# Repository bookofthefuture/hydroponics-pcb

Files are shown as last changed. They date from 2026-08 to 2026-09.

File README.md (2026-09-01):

# hydroponics-pcb

KiCad PCB designs for the hydroponics monitoring/control system on a two-tier
IKEA growing rack.

## Boards

| Board | Status | MCU | Purpose |
|---|---|-----|---|
| `tray-board` | fab-ready: ERC/DRC/schematic-parity clean, routed with GND pours + stitching, full JLC BOM (all Basic parts) / CPL / gerbers generated | socketed ESP32 30-pin DevKit | Per-tray sensor + display node. One per tray (top / bottom). |
| `reservoir-board` | not started | ESP32 (TBD) | Reservoir-side control: fill pumps, A/B + pH dosing pumps, level/EC/pH/temp sensing. |

Grow-lamp switching currently stays on the original ESP8266 `hydroponics_monitor`
node and is out of scope for these boards (may move to the reservoir board later).

## Tray board peripherals

| Function | Part | Bus | Notes |
|---|---|-----|---|
| ToF distance (water level) | VL53L0X / VL53L1X | I²C 3.3 V | Shared SDA/SCL |
| Air pressure (+ humidity/temp on BME) | BMP280 / BME280 | I²C 3.3 V | Shared SDA/SCL |
| Lux level | BH1750 | I²C 3.3 V | Shared SDA/SCL |
| Water temperature | DS18B20 | 1-Wire 3.3 V | Dedicated GPIO, 4.7 kΩ pull-up |
| User input | Rotary encoder + push switch | GPIO / quadrature | 3.3 V |
| Display | 2.4" ILI9341 240×320, resistive touch (XPT2046) + SD card | SPI (shared bus, separate CS lines) | LVGL, encoder-driven UI; SD card wired but not yet used by firmware |

Display connector (J2, 14-pin) pinout: VCC, GND, CS(D5), RESET(D4), DC(D2),
MOSI(D23), SCK(D18), LED(D15), MISO(D34), T_CLK(D18, shared), T_CS(D14),
T_DIN(D23, shared), T_DO(D34, shared), T_IRQ(D35). SD card connector (J3,
4-pin, separate from J2): CS(D19), MOSI(D23, shared), MISO(D34, shared),
SCK(D18, shared). New GPIOs used: 14, 19, 34, 35 — none of these were
previously assigned, so add them to the ESPHome configs without touching the
existing pin numbers.

No high-power switching on the tray board. An SP3485EN RS-485 transceiver
(120 Ω termination, direction pin on GPIO12) links the two tray boards to the
reservoir board.

## Comms

All three ESPs talk to Home Assistant over WiFi (ESPHome native API). The tray
boards *also* talk to the reservoir board over RS-485 — a local wired link so
fill-level reads and pump control don't depend on WiFi/HA. The reservoir is the
controlling node.

## Firmware

ESPHome configs live in the separate `ha-config` repo under `esphome/`
(`hydro-tray-top.yaml`, `hydro-tray-bottom.yaml`). The pin map is shared between
the schematic here and those configs — keep them in sync.

## Repo layout

```
tray-board/        KiCad project for the tray sensor board
reservoir-board/   (future) KiCad project for the reservoir board
shared-library/    custom symbol (New_Library) + footprint (Library.pretty)
                   library, referenced by both boards' sym-lib-table/
                   fp-lib-table via ${KIPRJMOD}/../../shared-library/ - keep
                   custom parts (ESP32 DevKit socket, display modules, etc.)
                   here rather than per-board copies, which drift silently
docs/              pin maps, block diagrams, datasheets
```

## Working with KiCad from the CLI

Requires KiCad 10.x (`kicad-cli`) plus the standard symbol/footprint libraries.

```
tools/fab.sh tray-board
```

runs ERC + DRC (fails on any error/warning) and writes a JLCPCB-ready set to
`tray-board/production/` (git-ignored — regenerated from source): gerbers
(Protel extensions) + separate PTH/NPTH Excellon drill files, zipped as
`<name>-gerbers.zip`; `<name>-cpl.csv` (SMD-only pick-and-place, DNP parts
excluded); `<name>-bom.csv` (DNP excluded, `LCSC Part #` column from each
part's `LCSC` schematic field). Parts you're sourcing/fitting yourself (e.g.
the socketed ESP32 module) should be marked Do Not Populate in the schematic
so they're left out of both the BOM and the CPL automatically.

It also runs `tools/check_pins.py`, which checks the MCU's pin usage for
hardware hazards ERC doesn't catch — currently ESP32 strapping pins (GPIO0,
2, 5, 12, 15) with an external pull that conflicts with their required
boot-time level, GPIO6-11 (internal flash, must never be used externally),
and UART0 (GPIO1/3, reserved for USB-serial). Fails the build on any
ERROR-severity finding; can also be run standalone:

```
tools/check_pins.py path/to/board.kicad_sch
```

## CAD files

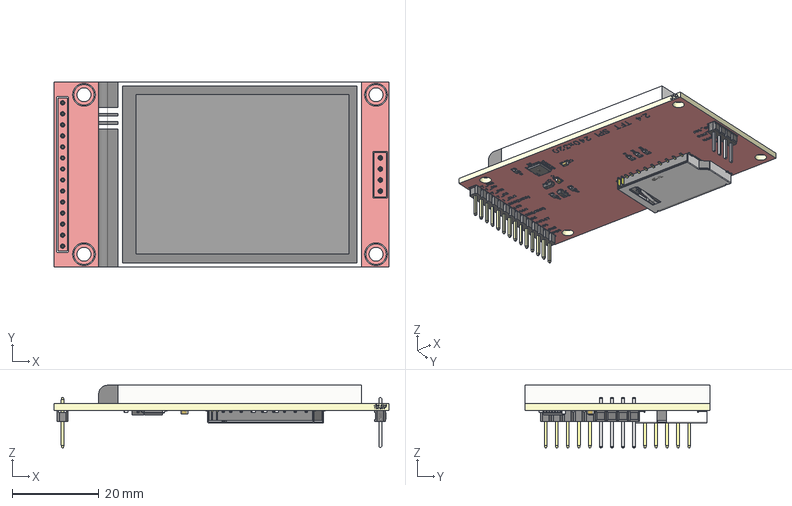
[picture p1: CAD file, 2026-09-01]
models/TFT LCD 2.4 inch ILI9341 touch.step
77.2 x 42.7 x 14.4 mm
Board~HwOR
TopSilkscreen~HwOR
BottomSilkscreen~HwOR
R0603~R0603~HwOR x 6
C0603~C0603_L1.6-W0.8-H0.8~HwOR x 2
HDR-TH_4P-P2.54-V-M~HDR-TH_4P-P2.54-M-LI-1X4P~HwOR
CONN-TH_PZ254V-11-14P~CONN-TH_PZ254V-11-14P~HwOR
SOT-23-3_L2.9-W1.3-P1.90-LS2.4-BR~SOT-23-3P_L2.9-W1.3-H1.0-LS2.4-P0.9 5~HwOR x 2
SD-CARD-SMD_SD-CARD-11P~SD-CARD-SMD_SD-CARD-11P~HwOR
TSSOP-16_L5.0-W4.4-P0.65-LS6.4-BL~TSSOP-16_L5.0-W4.4-H1.0-LS6.4-P0.65 ~HwOR
text

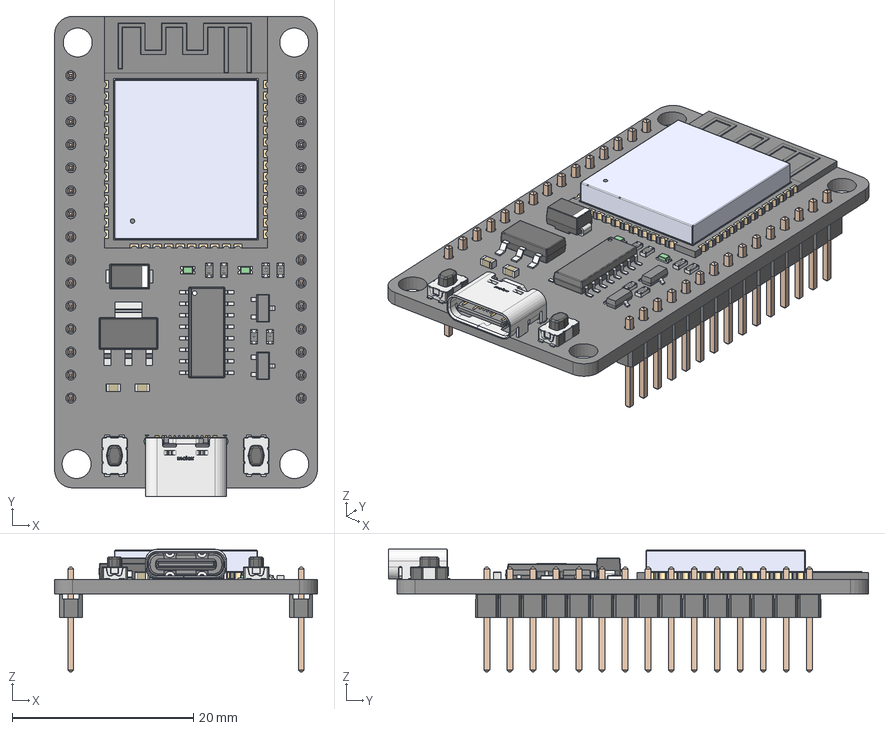
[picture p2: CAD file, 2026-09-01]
models/esp32_30pin.step
29.0 x 53.0 x 13.5 mm
6130xx11121_PIN x 30
SMA
0603 cap x 2
C&K - KMR7 x 2
0603 resistor x 6
LED 0603 Lens GREEN x 2
LED 0603 Base GREEN x 2
SOT-23-3 x 2
Leader x 16
SOT-223
Notch
Molex

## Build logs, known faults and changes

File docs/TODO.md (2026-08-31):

# Docs / tooling TODO

## Automated project documentation (web format)

**Goal:** generate a browsable project site from the repo, and make updating it part
of the deployment process rather than a separate chore.

Content it should pull together:

- Project overview / block diagram (tray boards + reservoir board + HA, WiFi + RS-485).
- Per-board pages: schematic render, PCB render (front/back), board specs
  (layers, size, thickness), revision.
- Links to artifacts: this repo, per-board 3D/STEP files, gerber zips, BOM, P&P.
- Deployment / assembly manual — for Tom and for anyone else building one:
  BOM sourcing, assembly order, flashing the ESPHome firmware, wiring the RS-485
  bus and sensor harnesses, first-power checks, calibration (EC/pH, ToF zero).

Ideas on how:

- `kicad-cli pcb render` + `pcb export svg/pdf` + `sch export svg` for the images.
- `kicad-cli pcb export step` for the 3D (needs `kicad-packages3d` installed).
- Static site — plain HTML, or MkDocs / Eleventy — published to GitHub Pages.
- A `tools/docs.sh` that regenerates images + site from source; call it from the
  release/deploy flow so docs can't drift from the hardware.
- Version the deployment manual alongside the board revision it describes.

Not started — captured 2026-08-28.

## Tray-board display connector footprint (for the redesign)

`docs/datasheets/MSP2401_2.4in_TFT_touch_SD_mechanical.pdf` — mechanical
drawing for the LCD Wiki MSP2401/MSP2402 2.4" ILI9341+XPT2046 module.
Confirmed against the physical board (2026-08-31) — this is the correct
footprint, not just a probable match.

Dimensioned numbers from this drawing, all confirmed against physical
measurement:
- PCB outline: 42.72 x 77.18mm
- Main 14-pin header (J2): 2.54mm pitch, 33.02mm span (13 gaps), pin 1
  at X=4.85mm, Y=75.18mm (2.00mm up from the bottom edge) from the
  top-left PCB corner
- SD card header (J4): 4 pins, 2.54mm pitch, pin 1 at X=17.23mm,
  Y=3.00mm from the top-left PCB corner (same row as the two top
  mounting holes)
- 4 mounting holes: 3.20mm drill / 4.70mm pad, at 36.72mm x 67.26mm
  hole-to-hole spacing, inset 3.00mm from each edge

All of the above is already built as a footprint:
`shared-library/Library.pretty/Display_MSP2401_2.4in_Touch.kicad_mod`
(outline, mounting holes, J2 pins 1-14, J4 pins SD1-SD4) — use it
directly for correct connector spacing in the redesign rather than
re-deriving these numbers.

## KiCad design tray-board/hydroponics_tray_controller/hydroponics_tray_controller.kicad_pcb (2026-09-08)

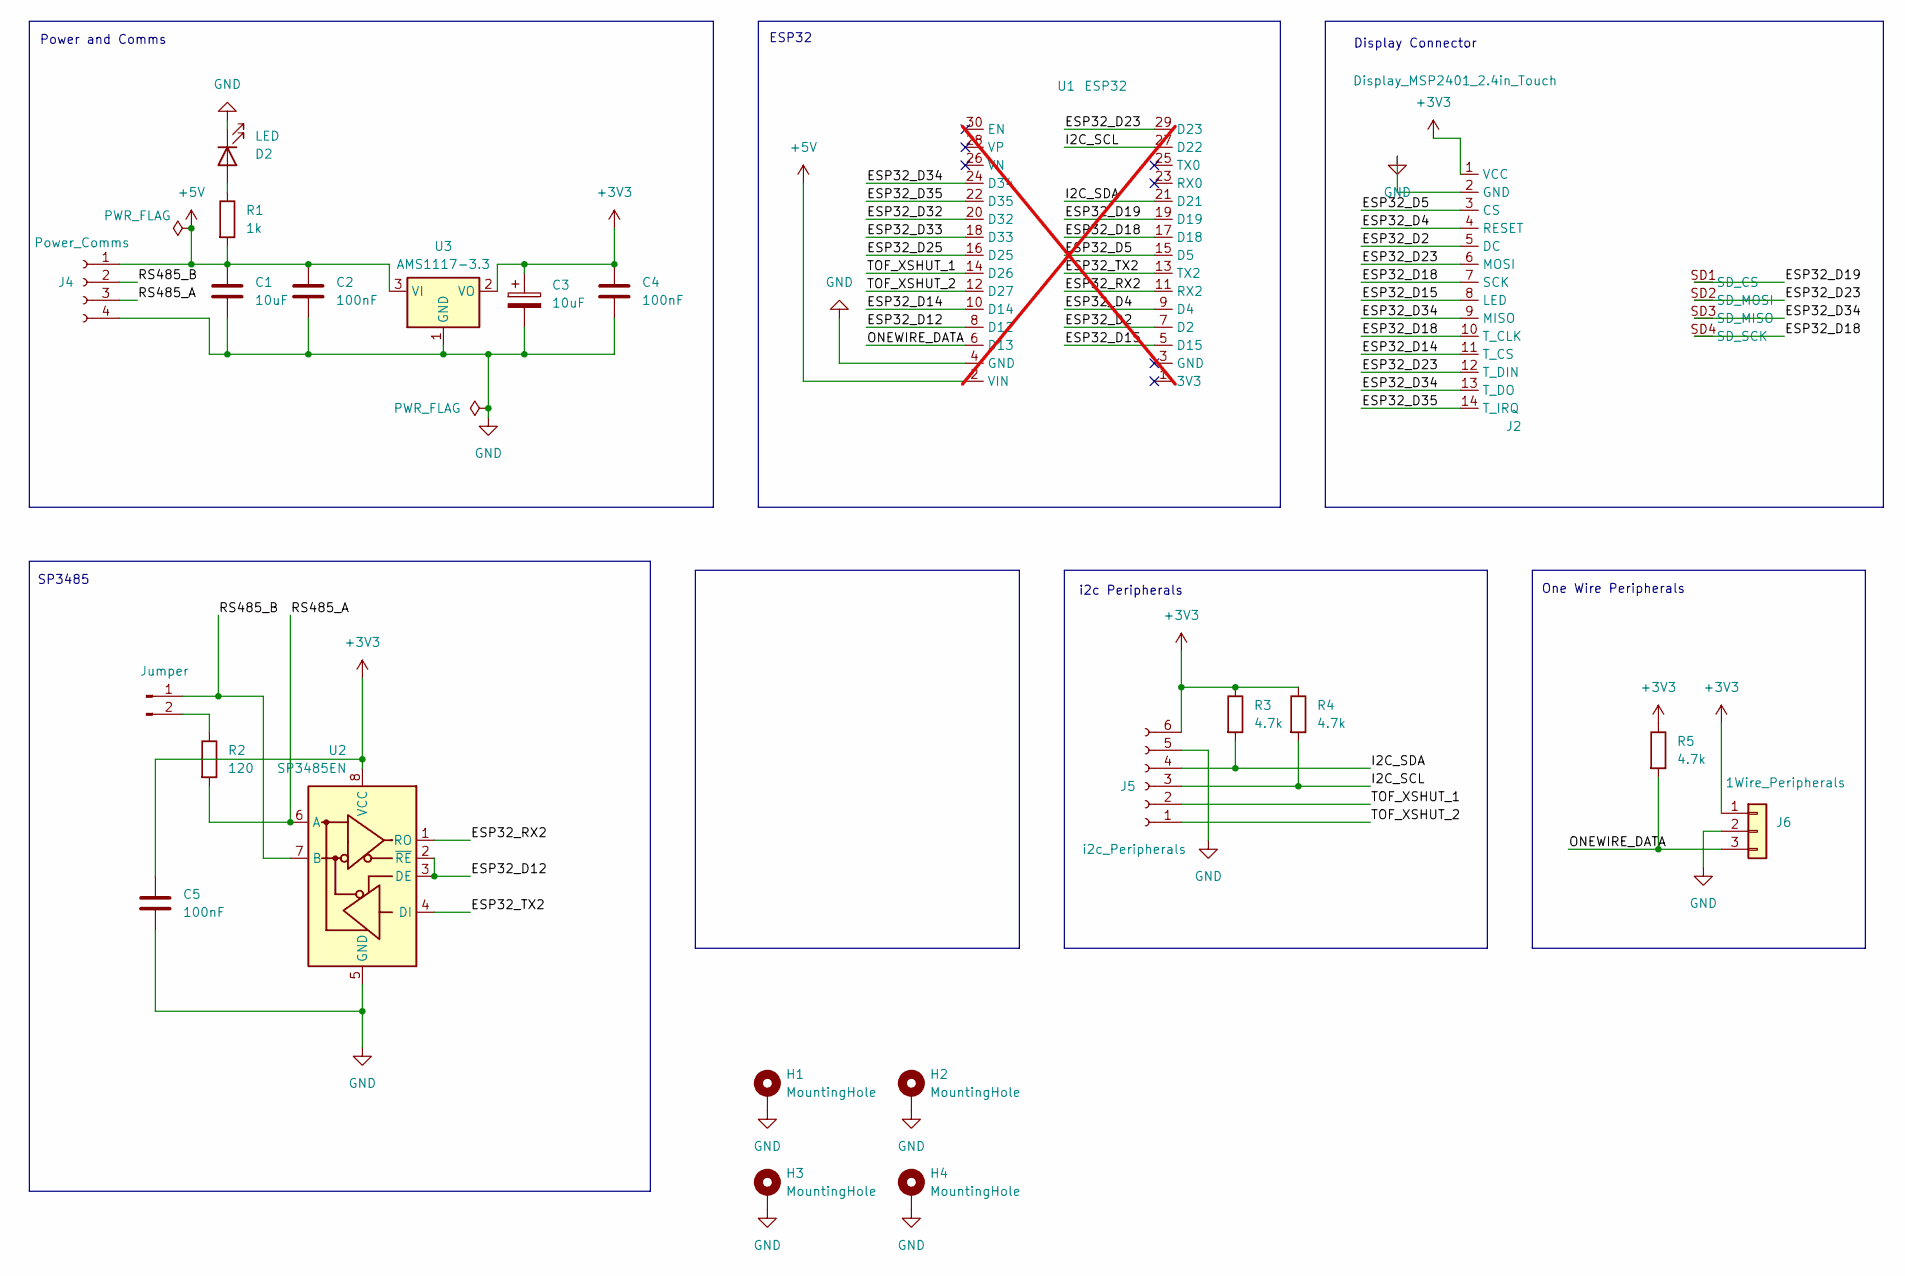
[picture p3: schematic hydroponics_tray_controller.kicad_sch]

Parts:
C1: 10uF; C_1206_3216Metric; LCSC C13585
C2, C4, C5: 100nF; C_0805_2012Metric; LCSC C49678
C3: 10uF; C_0805_2012Metric; LCSC C15850
D2: LED; LED_0805_2012Metric; LCSC C2297
H1, H2, H3, H4: MountingHole; MountingHole_3.2mm_M3_Pad_Via
J1: Jumper; PinHeader_1x02_P2.54mm_Vertical
J2: Display_MSP2401_2.4in_Touch
J4: Power_Comms; JST_XH_B4B-XH-A_1x04_P2.50mm_Vertical
J5: i2c_Peripherals; JST_XH_B6B-XH-A_1x06_P2.50mm_Vertical
J6: 1Wire_Peripherals; JST_XH_B3B-XH-A_1x03_P2.50mm_Vertical
R1: 1k; R_0805_2012Metric; LCSC C17513
R2: 120; R_0805_2012Metric; LCSC C17437
R3, R4, R5: 4.7k; R_0805_2012Metric; LCSC C17673
U1: ESP32; ESP32_DevKit_30Pin; not fitted
U2: SP3485EN; SOIC-8_3.9x4.9mm_P1.27mm; LCSC C8963
U3: AMS1117-3.3; SOT-223-3_TabPin2; LCSC C6186

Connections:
+3V3: C3.1, C4.1, C5.1, J2.1 (VCC), J5.6, J6.1, R3.1, R4.1, R5.1, U2.8 (VCC), U3.2 (VO)
+5V: C1.1, C2.1, J4.1, R1.2, U1.2 (VIN), U3.3 (VI)
/ESP32_D2: J2.5 (DC), U1.7 (D2)
/ESP32_D4: J2.4 (RESET), U1.9 (D4)
/ESP32_D5: J2.3 (CS), U1.15 (D5)
/ESP32_D12: U1.8 (D12), U2.2 (~RE), U2.3 (DE)
/ESP32_D14: J2.11 (T_CS), U1.10 (D14)
/ESP32_D15: J2.8 (LED), U1.5 (D15)
/ESP32_D18: J2.7 (SCK), J2.10 (T_CLK), J2.SD4 (SD_SCK), U1.17 (D18)
/ESP32_D19: J2.SD1 (SD_CS), U1.19 (D19)
/ESP32_D23: J2.6 (MOSI), J2.12 (T_DIN), J2.SD2 (SD_MOSI), U1.29 (D23)
/ESP32_D25: U1.16 (D25)
/ESP32_D32: U1.20 (D32)
/ESP32_D33: U1.18 (D33)
/ESP32_D34: J2.9 (MISO), J2.13 (T_DO), J2.SD3 (SD_MISO), U1.24 (D34)
/ESP32_D35: J2.14 (T_IRQ), U1.22 (D35)
/ESP32_RX2: U1.11 (RX2), U2.1 (RO)
/ESP32_TX2: U1.13 (TX2), U2.4 (DI)
/I2C_SCL: J5.3, R4.2, U1.27 (D22)
/I2C_SDA: J5.4, R3.2, U1.21 (D21)
/ONEWIRE_DATA: J6.3, R5.2, U1.6 (D13)
/RS485_A: J4.3, R2.2, U2.6 (A)
/RS485_B: J1.1, J4.2, U2.7 (B)
/TOF_XSHUT_1: J5.2, U1.14 (D26)
/TOF_XSHUT_2: J5.1, U1.12 (D27)
GND: C1.2, C2.2, C3.2, C4.2, C5.2, D2.1 (K), H1.1 (1_1), H2.1 (1_1), H3.1 (1_1), H4.1 (1_1), J2.2 (GND), J4.4, J5.5, J6.2, U1.4 (GND), U2.5 (GND), U3.1 (GND)
unnamed: D2.2 (A), R1.1
unnamed: J1.2, R2.1

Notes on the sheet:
One Wire Peripherals
SP3485
ESP32
Display Connector
i2c Peripherals
Power and Comms

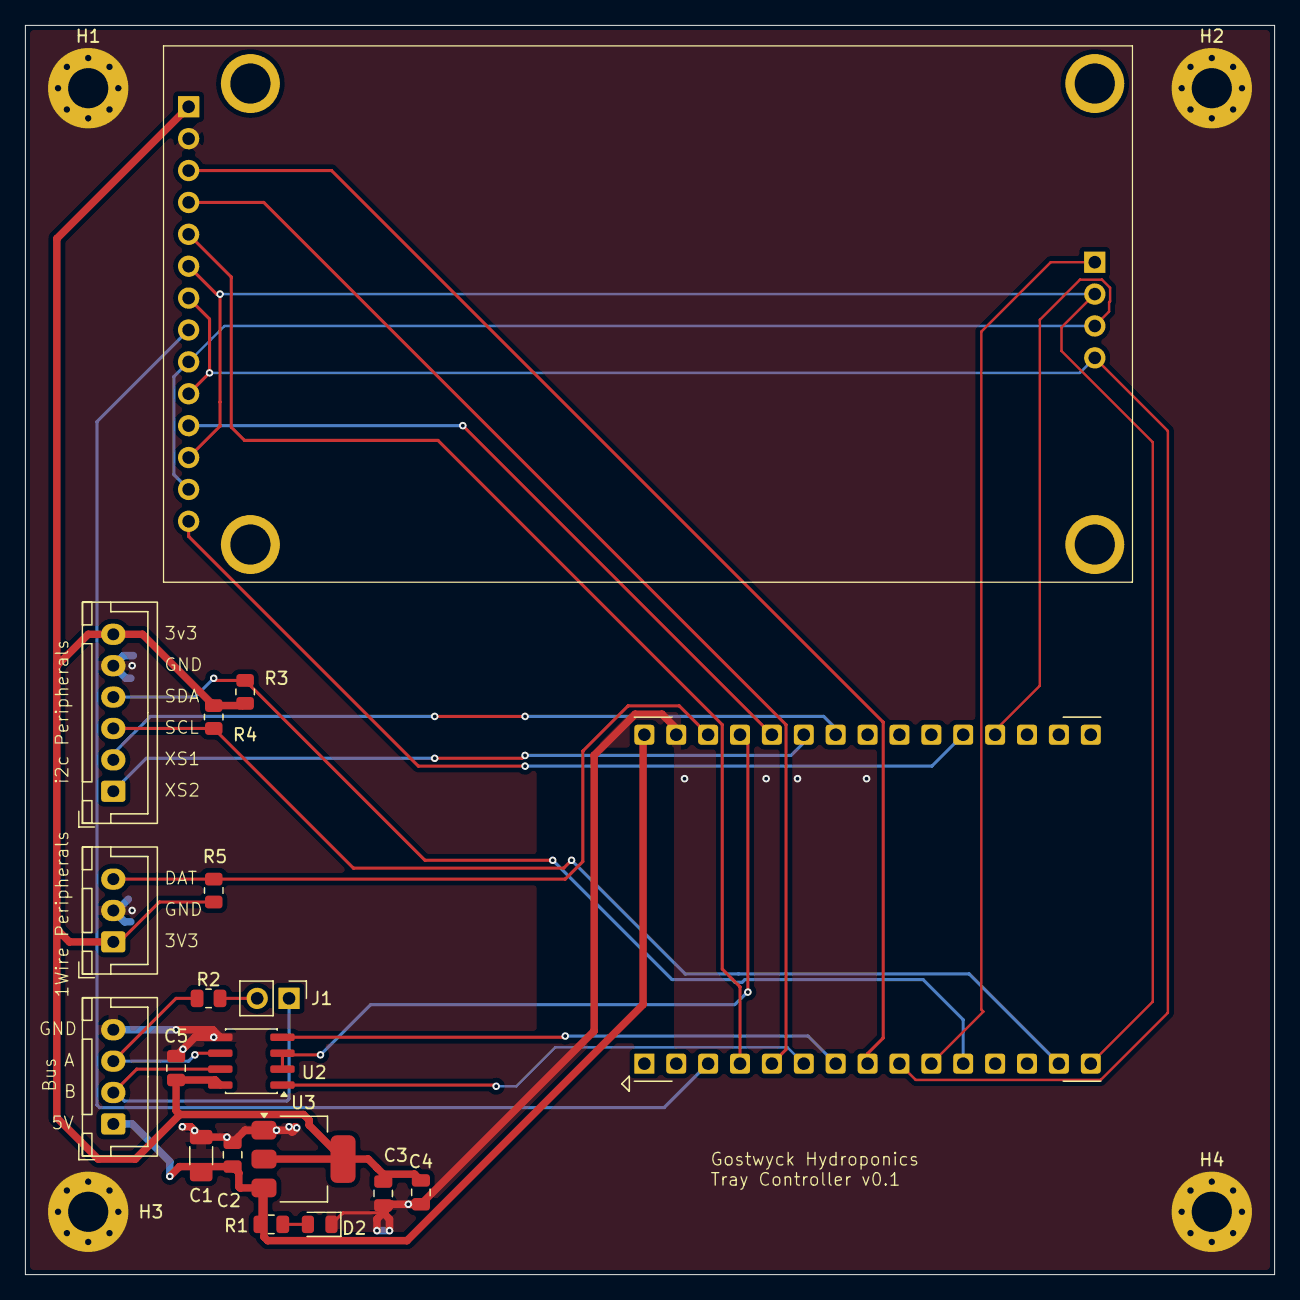
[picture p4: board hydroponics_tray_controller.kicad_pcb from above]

Board: 2 copper layers, 99.5 x 99.5 mm, 23 parts (0 on the bottom side), 25 nets.

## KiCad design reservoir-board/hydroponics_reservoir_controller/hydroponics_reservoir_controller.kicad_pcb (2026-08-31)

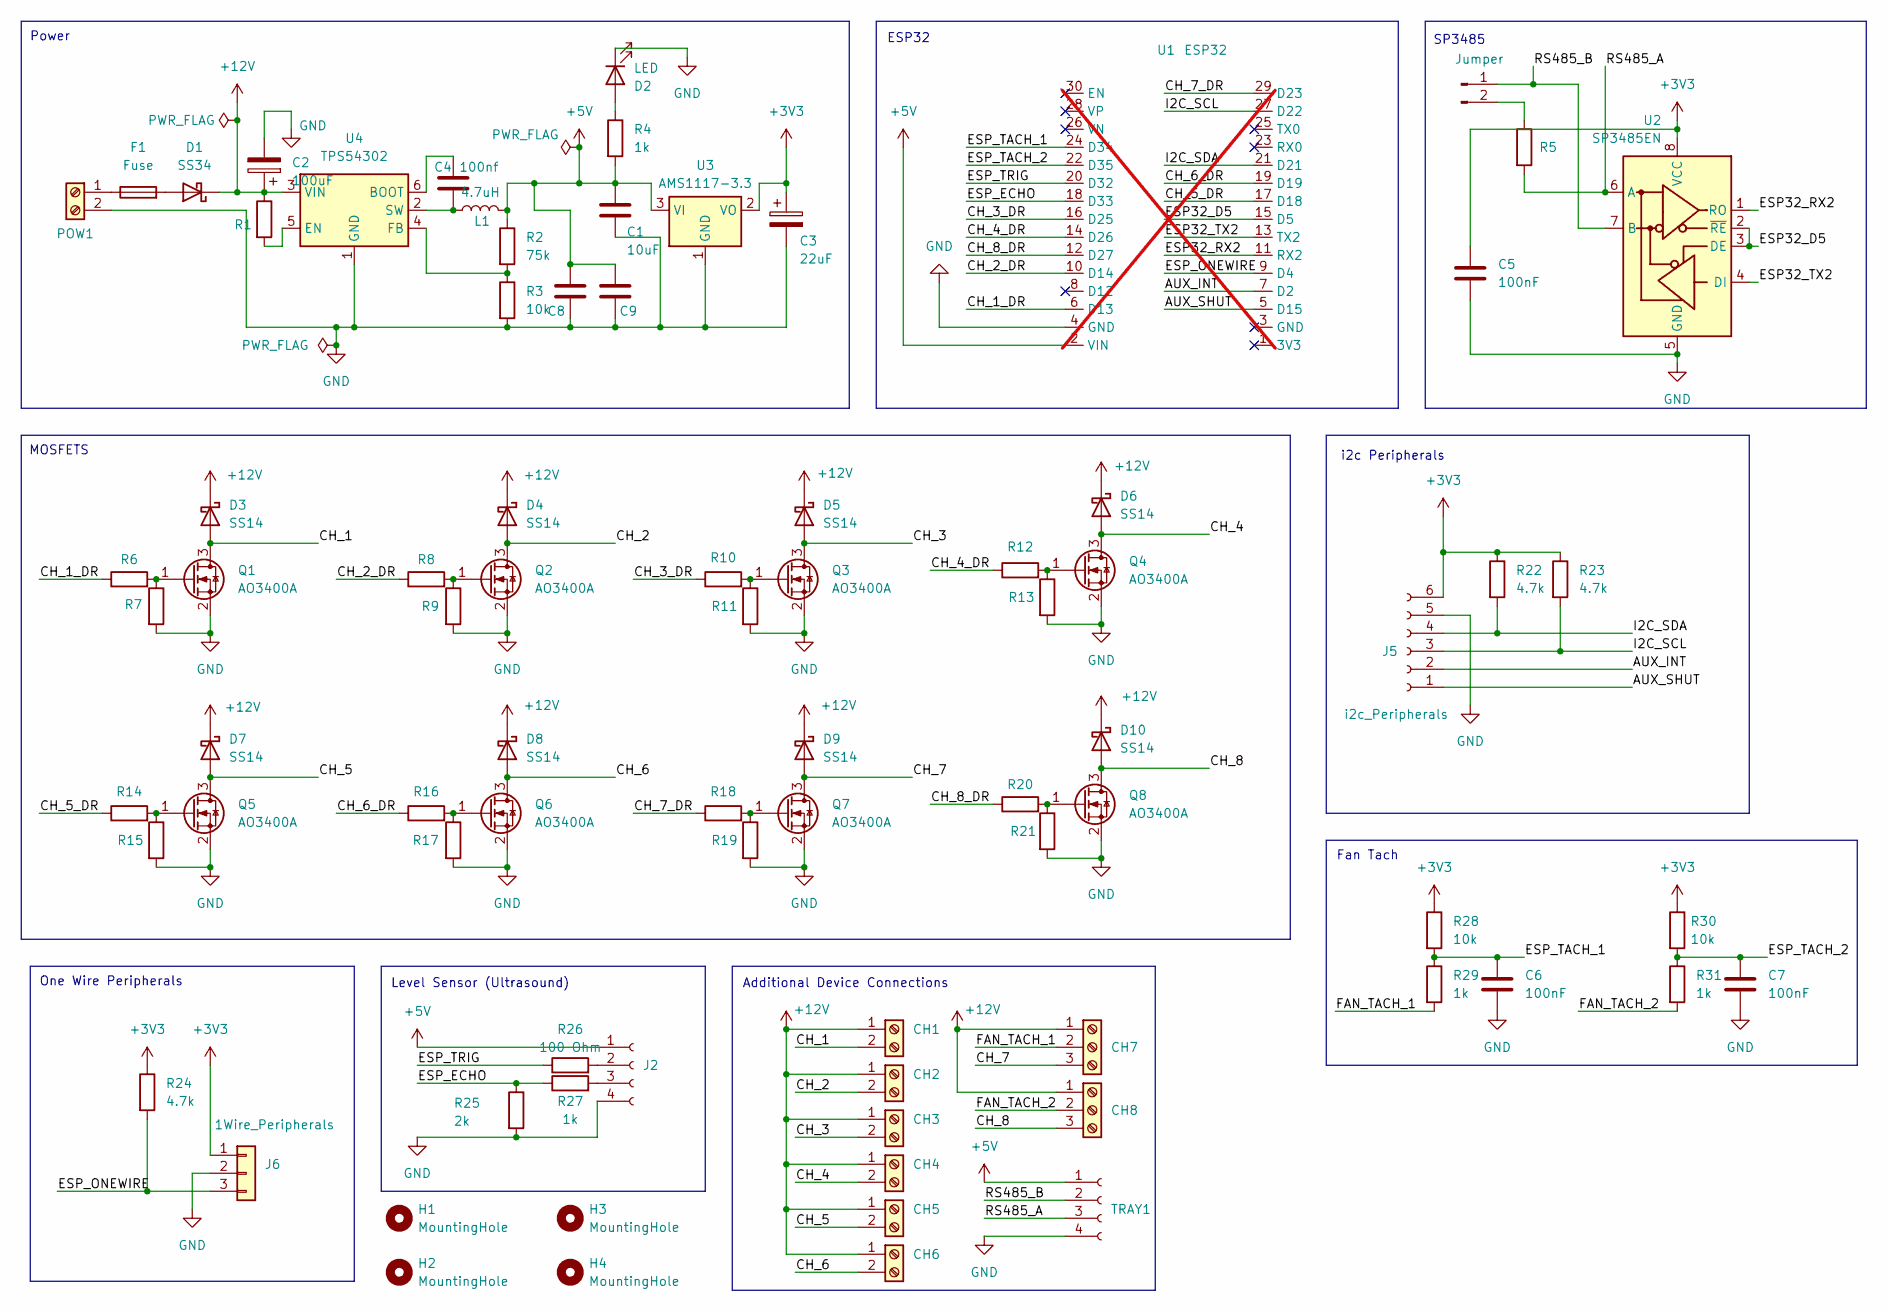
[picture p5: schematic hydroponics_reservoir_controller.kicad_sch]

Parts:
C1: 10uF; C_1206_3216Metric; LCSC C2443257
C2: 100uF; CP_Elec_6.3x7.7; LCSC C970685
C3: 22uF; CP_EIA-3528-21_Kemet-B; LCSC C24518
C4: 100nf; C_1206_3216Metric; LCSC C93194
C5, C6, C7: 100nF; C_0805_2012Metric; LCSC C83055
C8, C9: 22uF; C_1206_3216Metric; LCSC C105213
CH1, CH2, CH3, CH4, CH5, CH6: Screw_Terminal_01x02; TerminalBlock_Phoenix_PT-1,5-2-3.5-H_1x02_P3.50mm_Horizontal; LCSC C474892
CH7, CH8: Screw_Terminal_01x03; TerminalBlock_Phoenix_PT-1,5-3-3.5-H_1x03_P3.50mm_Horizontal; LCSC C474893
D1: SS34; D_SMA; LCSC C8678
D2: LED; LED_0805_2012Metric; LCSC C84260
D3, D4, D5, D6, D7, D8, D9, D10: SS14; D_SMA; LCSC C1508
F1: Fuse; Fuse_2920_7451Metric; LCSC C207091
H1, H2, H3, H4: MountingHole; MountingHole_3.2mm_M3_Pad
J1: Jumper; PinHeader_1x02_P2.54mm_Vertical; LCSC C36717
J2: Conn_01x04_Socket; JST_XH_B4B-XH-A_1x04_P2.50mm_Vertical; LCSC C144395
J5: i2c_Peripherals; JST_XH_B6B-XH-A_1x06_P2.50mm_Vertical; LCSC C144397
J6: 1Wire_Peripherals; JST_XH_B3B-XH-A_1x03_P2.50mm_Vertical; LCSC C144394
L1: 4.7uH; L_Bourns_SRP6060FA; LCSC C2047389
POW1: Screw_Terminal_01x02; TerminalBlock_Phoenix_PT-1,5-2-5.0-H_1x02_P5.00mm_Horizontal; LCSC C474881
Q1, Q2, Q3, Q4, Q5, Q6, Q7, Q8: AO3400A; SOT-23; LCSC C20917
R1: 100k; R_0805_2012Metric; LCSC C17407
R2: 75k; R_0805_2012Metric; LCSC C17819
R3, R7, R9, R11, R13, R15, R17, R19, R21, R28, R30: 10k; R_0805_2012Metric; LCSC C17414
R4, R27, R29, R31: 1k; R_0805_2012Metric; LCSC C17513
R5: 120 Ohm; R_0805_2012Metric; LCSC C17437
R6, R8, R10, R12, R14, R16, R18, R20, R26: 100 Ohm; R_0805_2012Metric; LCSC C17408
R22, R23, R24: 4.7k; R_0805_2012Metric; LCSC C17673
R25: 2k; R_0805_2012Metric; LCSC C17604
TRAY1: Conn_01x04_Socket; JST_XH_B4B-XH-A_1x04_P2.50mm_Vertical; LCSC C144395
U1: ESP32; ESP32_DevKit_30Pin; not fitted
U2: SP3485EN; SOIC-8_3.9x4.9mm_P1.27mm; LCSC C8963
U3: AMS1117-3.3; SOT-223-3_TabPin2; LCSC C6186
U4: TPS54302; SOT-23-6; LCSC C311983

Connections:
+3V3: C3.1, C5.1, J5.6, J6.1, R22.1, R23.1, R24.1, R28.1, R30.1, U2.8 (VCC), U3.2 (VO); also elsewhere on the board
+5V: C1.1, C8.1, C9.1, J2.1, L1.2, R2.1, R4.2, TRAY1.1, U1.2 (VIN), U3.3 (VI); also elsewhere on the board
/AUX_INT: J5.2, U1.7 (D2); also elsewhere on the board
/AUX_SHUT: J5.1, U1.5 (D15); also elsewhere on the board
/CH_1: CH1.2, D3.2 (A), Q1.3 (D)
/CH_1_DR: R6.1, U1.6 (D13)
/CH_2: CH2.2, D4.2 (A), Q2.3 (D)
/CH_2_DR: R8.1, U1.10 (D14)
/CH_3: CH3.2, D5.2 (A), Q3.3 (D)
/CH_3_DR: R10.1, U1.16 (D25)
/CH_4: CH4.2, D6.2 (A), Q4.3 (D)
/CH_4_DR: R12.1, U1.14 (D26)
/CH_5: CH5.2, D7.2 (A), Q5.3 (D)
/CH_5_DR: R14.1, U1.17 (D18)
/CH_6: CH6.2, D8.2 (A), Q6.3 (D)
/CH_6_DR: R16.1, U1.19 (D19)
/CH_7: CH7.3, D9.2 (A), Q7.3 (D)
/CH_7_DR: R18.1, U1.29 (D23)
/CH_8: CH8.3, D10.2 (A), Q8.3 (D)
/CH_8_DR: R20.1, U1.12 (D27)
/ESP32_D5: U1.15 (D5), U2.2 (~RE), U2.3 (DE)
/ESP32_RX2: U1.11 (RX2), U2.1 (RO)
/ESP32_TX2: U1.13 (TX2), U2.4 (DI)
/ESP_ECHO: R25.1, R27.1, U1.18 (D33)
/ESP_ONEWIRE: J6.3, R24.2, U1.9 (D4); also elsewhere on the board
/ESP_TACH_1: C6.1, R28.2, R29.1, U1.24 (D34)
/ESP_TACH_2: C7.1, R30.2, R31.1, U1.22 (D35)
/ESP_TRIG: R26.1, U1.20 (D32)
/FAN_TACH_1: CH7.2, R29.2
/FAN_TACH_2: CH8.2, R31.2
/I2C_SCL: J5.3, R23.2, U1.27 (D22); also elsewhere on the board
/I2C_SDA: J5.4, R22.2, U1.21 (D21); also elsewhere on the board
/RS485_A: R5.2, TRAY1.3, U2.6 (A); also elsewhere on the board
/RS485_B: J1.1, TRAY1.2, U2.7 (B); also elsewhere on the board
GND: C1.2, C2.2, C3.2, C5.2, C6.2, C7.2, C8.2, C9.2, D2.1 (K), J2.4, J5.5, J6.2, POW1.2, Q1.2 (S), Q2.2 (S), Q3.2 (S), Q4.2 (S), Q5.2 (S), Q6.2 (S), Q7.2 (S), Q8.2 (S), R3.2, R7.2, R9.2, R11.2, R13.2, R15.2, R17.2, R19.2, R21.2, R25.2, TRAY1.4, U1.4 (GND), U2.5 (GND), U3.1 (GND), U4.1 (GND); also elsewhere on the board
unnamed: D1.2 (A), F1.2
unnamed: D2.2 (A), R4.1
unnamed: J1.2, R5.1
unnamed 38: J2.2, R26.2; also elsewhere on the board
unnamed 39: J2.3, R27.2; also elsewhere on the board
unnamed: Q1.1 (G), R6.2, R7.1
unnamed: Q2.1 (G), R8.2, R9.1
unnamed: Q3.1 (G), R10.2, R11.1
unnamed: Q4.1 (G), R12.2, R13.1
unnamed: Q5.1 (G), R14.2, R15.1
unnamed: Q6.1 (G), R16.2, R17.1
unnamed: Q7.1 (G), R18.2, R19.1
unnamed: Q8.1 (G), R20.2, R21.1
unnamed: C4.1, U4.6 (BOOT)
unnamed: R1.2, U4.5 (EN)
unnamed: R2.2, R3.1, U4.4 (FB)
unnamed: C4.2, L1.1, U4.2 (SW)

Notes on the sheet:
One Wire Peripherals
Additional Device Connections
SP3485
ESP32
MOSFETS
Level Sensor (Ultrasound)
Fan Tach
i2c Peripherals
Power

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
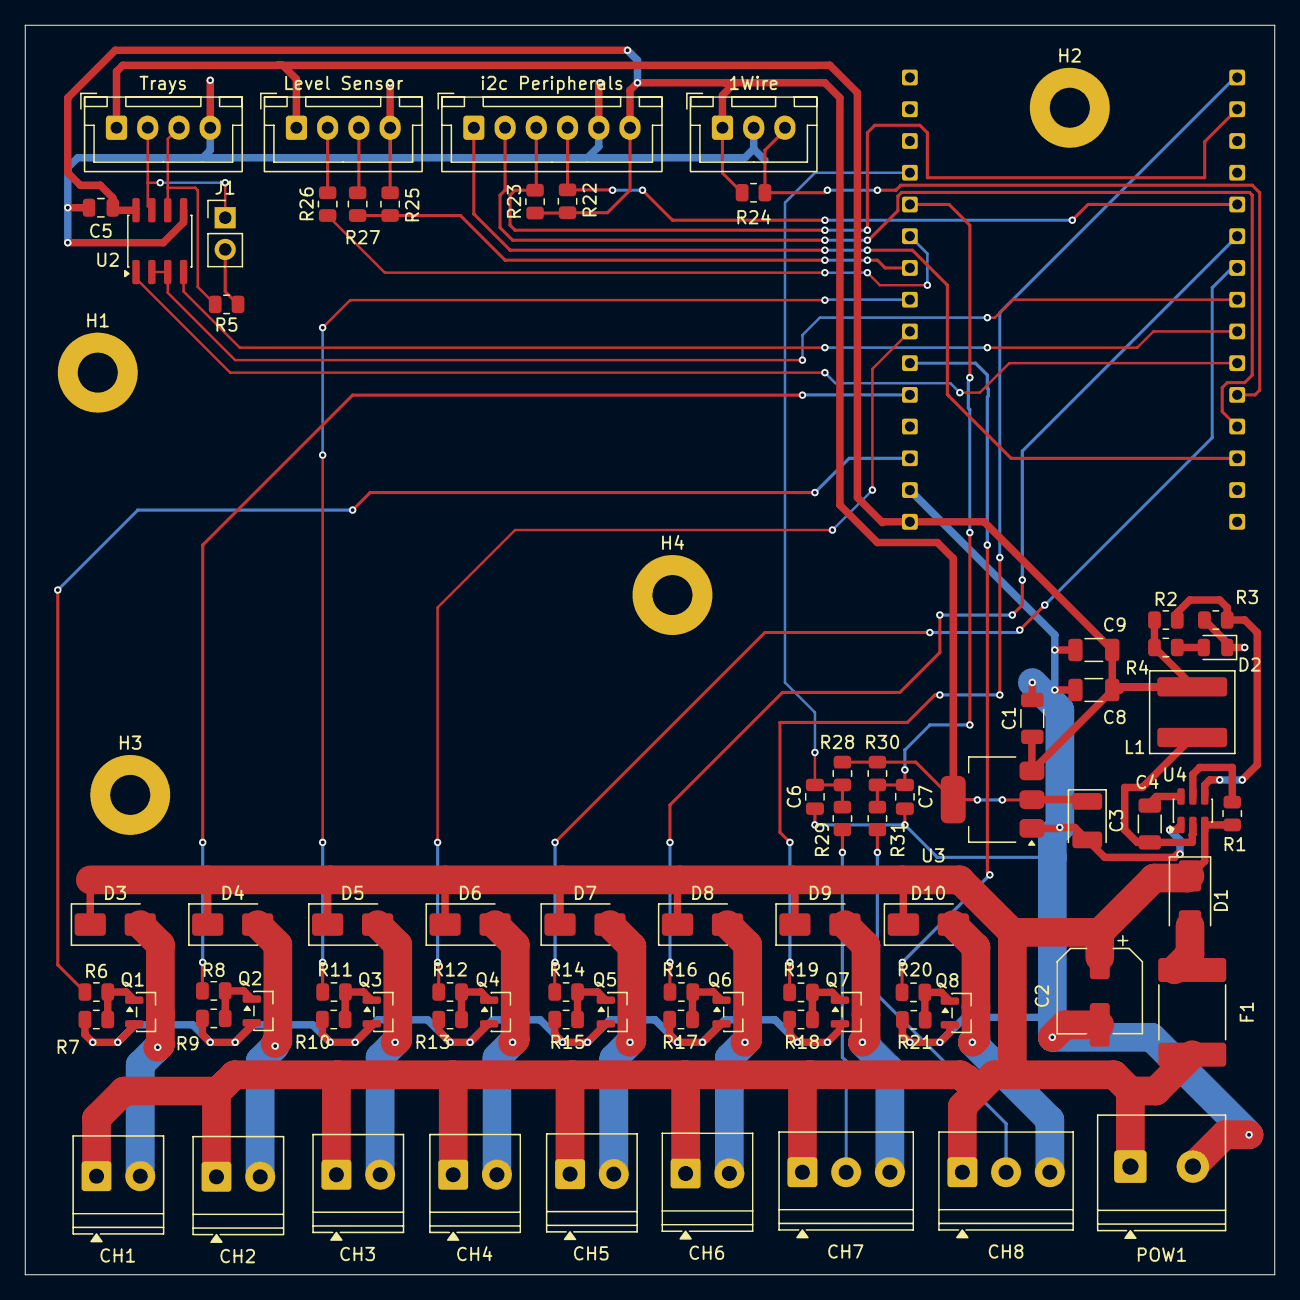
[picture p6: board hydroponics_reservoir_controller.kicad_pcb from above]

Board: 2 copper layers, 100.0 x 100.0 mm, 82 parts (0 on the bottom side), 53 nets.

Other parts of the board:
1Wire: 1Wire_Peripherals; JST_XH_B3B-XH-A_1x03_P2.50mm_Vertical
Level Sensor: Conn_01x04_Socket; JST_XH_B4B-XH-A_1x04_P2.50mm_Vertical
Trays: Conn_01x04_Socket; JST_XH_B4B-XH-A_1x04_P2.50mm_Vertical
i2c Peripherals: i2c_Peripherals; JST_XH_B6B-XH-A_1x06_P2.50mm_Vertical

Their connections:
+3V3: 1Wire.1, i2c Peripherals.6; also elsewhere on the board
+5V: Level Sensor.1, Trays.1; also elsewhere on the board
/AUX_INT: i2c Peripherals.2; also elsewhere on the board
/AUX_SHUT: i2c Peripherals.1; also elsewhere on the board
/ESP_ONEWIRE: 1Wire.3; also elsewhere on the board
/I2C_SCL: i2c Peripherals.3; also elsewhere on the board
/I2C_SDA: i2c Peripherals.4; also elsewhere on the board
/RS485_A: Trays.3; also elsewhere on the board
/RS485_B: Trays.2; also elsewhere on the board
GND: 1Wire.2, Level Sensor.4, Trays.4, i2c Peripherals.5; also elsewhere on the board
unnamed 38: Level Sensor.2; also elsewhere on the board
unnamed 39: Level Sensor.3; also elsewhere on the board

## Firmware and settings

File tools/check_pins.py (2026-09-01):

#!/usr/bin/env python3
"""
Check MCU pin usage in a KiCad schematic for hardware-boot / strapping-pin
hazards before it goes to production. Currently has a rule set for the
ESP32 (strapping pins, input-only pins, reserved-flash pins, UART0).

Usage:
    tools/check_pins.py <path-to.kicad_sch>

Exits non-zero if any ERROR-severity issue is found (matches the
ERC/DRC convention used by tools/fab.sh).
"""

import os
import re
import subprocess
import sys
import tempfile
from pathlib import Path

# --- ESP32 pin rules -------------------------------------------------------
# Keyed by the pin "name" as it appears in the schematic symbol (before the
# trailing "_<pinnumber>" KiCad appends to pinfunction in the netlist).
#
# bad_pull: "up" | "down" | None  - an external pull in this direction on the
#   net conflicts with the pin's required state during the ESP32 boot/reset
#   window (before firmware takes over).
STRAPPING_RULES = {
    "D0": {
        "severity": "error",
        "bad_pull": "down",
        "note": "GPIO0 (BOOT) must be HIGH at reset for normal boot; an "
                "external pull-down (or hard tie to GND) forces download "
                "mode and the board will not run firmware.",
    },
    "D2": {
        "severity": "error",
        "bad_pull": "up",
        "note": "GPIO2 must be LOW or floating at reset for normal SPI "
                "boot; an external pull-up can prevent the board from "
                "booting.",
    },
    "D5": {
        "severity": "warning",
        "bad_pull": "down",
        "note": "GPIO5 should be HIGH at reset (affects VSPI/boot timing "
                "default on some modules); an external pull-down may cause "
                "intermittent boot issues.",
    },
    "D12": {
        "severity": "error",
        "bad_pull": "up",
        "note": "GPIO12 (MTDI) selects flash voltage at reset. An external "
                "pull-up forces 1.8V flash detection and will break boot "
                "on the (standard) 3.3V-flash modules this project uses.",
    },
    "D15": {
        "severity": "info",
        "bad_pull": None,
        "note": "GPIO15 (MTDO) LOW silences the ROM boot log on UART0; "
                "HIGH (its internal pull-up default) is functionally fine, "
                "just noisier on the console.",
    },
}

INPUT_ONLY_PINS = {"D34", "D35", "VP", "VN"}
UART0_PINS = {"RX0", "TX0"}
RESERVED_FLASH_PINS = {"D6", "D7", "D8", "D9", "D10", "D11"}

POWER_NET_POSITIVE = re.compile(r"^\+?(3V3|5V|VCC|VDD)$", re.I)
POWER_NET_GROUND = re.compile(r"^(GND|AGND|DGND)$", re.I)


def run_netlist_export(sch_path: Path, out_path: Path) -> None:
    kicad_cli = os.environ.get("KICAD_CLI", "kicad-cli")
    subprocess.run(
        [
            kicad_cli, "sch", "export", "netlist",
            "--format", "kicadsexpr",
            "-o", str(out_path),
            str(sch_path),
        ],
        check=True,
        capture_output=True,
        text=True,
    )


def parse_netlist(text: str):
    """Return (components: {ref: part_name}, nets: [{name, nodes:[(ref,pin,pinfunction,pintype)]}])."""
    components = {}
    for comp_block in re.finditer(
        r'\(comp\s*\n\s*\(ref "([^"]+)"\).*?\(libsource\s*\n\s*\(lib "[^"]*"\)\s*\n\s*\(part "([^"]*)"\)',
        text, re.S,
    ):
        ref, part = comp_block.groups()
        components[ref] = part

    nets = []
    net_blocks = re.split(r"\n\t\t\(net\n", text)
    for block in net_blocks[1:]:
        block = "\t\t(net\n" + block
        name_m = re.search(r'\(name "([^"]*)"\)', block)
        name = name_m.group(1) if name_m else ""
        nodes = re.findall(
            r'\(ref "([^"]+)"\)\s*\(pin "([^"]+)"\)\s*(?:\(pinfunction "([^"]*)"\)\s*)?\(pintype "([^"]*)"\)',
            block,
        )
        nets.append({"name": name, "nodes": nodes})
    return components, nets


def pin_name_from_function(pinfunction: str, pin_number: str) -> str:
    if not pinfunction:
        return pin_number
    suffix = f"_{pin_number}"
    if pinfunction.endswith(suffix):
        return pinfunction[: -len(suffix)]
    return pinfunction


def main():
    if len(sys.argv) != 2:
        print(__doc__)
        sys.exit(2)

    sch_path = Path(sys.argv[1]).resolve()
    if not sch_path.exists():
        print(f"error: {sch_path} not found", file=sys.stderr)
        sys.exit(2)

    with tempfile.TemporaryDirectory() as tmp:
        nl_path = Path(tmp) / "check_pins.net"
        try:
            run_netlist_export(sch_path, nl_path)
        except subprocess.CalledProcessError as e:
            print("error: kicad-cli netlist export failed", file=sys.stderr)
            print(e.stderr, file=sys.stderr)
            sys.exit(2)
        text = nl_path.read_text()

    components, nets = parse_netlist(text)

    mcu_refs = [ref for ref, part in components.items() if "esp32" in part.lower()]
    if not mcu_refs:
        print("check_pins: no ESP32 symbol found in this schematic — nothing to check.")
        sys.exit(0)

    # net lookup: (ref, pin) -> net dict, for tracing pull-resistor legs
    pin_to_net = {}
    for net in nets:
        for ref, pin, _pf, _pt in net["nodes"]:
            pin_to_net[(ref, pin)] = net

    findings = []  # (severity, message)

    checked_strapping = []  # (pname, ref, pin) with no hazard found

    for net in nets:
        mcu_nodes = [n for n in net["nodes"] if n[0] in mcu_refs]
        if not mcu_nodes:
            continue
        # KiCad gives every truly-unconnected pin its own placeholder net
        # named "unconnected-(...)" — nothing is actually wired there.
        is_unconnected = net["name"].startswith("unconnected-")

        for ref, pin, pinfunction, _pintype in mcu_nodes:
            pname = pin_name_from_function(pinfunction, pin)

            if is_unconnected:
                continue

            if pname in RESERVED_FLASH_PINS:
                findings.append((
                    "error",
                    f"{ref} pin {pin} ({pname}) is one of the ESP32's internal "
                    f"SPI-flash pins (GPIO6-11) and is wired to net "
                    f"'{net['name']}'. These must never be used externally on "
                    f"a module with integrated flash.",
                ))
                continue

            if pname in UART0_PINS:
                findings.append((
                    "warning",
                    f"{ref} pin {pin} ({pname}) is UART0 (USB-serial console "
                    f"/ flashing) and is wired to net '{net['name']}'. Using "
                    f"it for anything else will conflict with programming "
                    f"and the serial monitor.",
                ))

            if pname in INPUT_ONLY_PINS:
                findings.append((
                    "info",
                    f"{ref} pin {pin} ({pname}) is input-only (no internal "
                    f"pull, cannot be driven as an output) on net "
                    f"'{net['name']}'. Confirm nothing expects the ESP32 to "
                    f"drive this line (e.g. as a chip-select or reset).",
                ))

            rule = STRAPPING_RULES.get(pname)
            if not rule:
                continue

            # Direct hard-tie to a power net (net IS the power rail).
            if POWER_NET_POSITIVE.match(net["name"]) or POWER_NET_GROUND.match(net["name"]):
                pulled = "up" if POWER_NET_POSITIVE.match(net["name"]) else "down"
                if rule["bad_pull"] and pulled == rule["bad_pull"]:
                    findings.append((rule["severity"],
                        f"{ref} pin {pin} ({pname}) is hard-tied to "
                        f"{net['name']} — {rule['note']}"))
                else:
                    findings.append(("info",
                        f"{ref} pin {pin} ({pname}) is hard-tied to "
                        f"{net['name']} (likely intentional strapping) — "
                        f"verify this is deliberate."))
                continue

            # Look for a pull resistor: another node on this net that is a
            # 2-pin resistor whose OTHER leg lands on a power net.
            bad_pull_found = False
            for other_ref, other_pin, _opf, _opt in net["nodes"]:
                if other_ref == ref or not other_ref.startswith("R"):
                    continue
                other_leg = "2" if other_pin == "1" else "1"
                far_net = pin_to_net.get((other_ref, other_leg))
                if not far_net:
                    continue
                if POWER_NET_POSITIVE.match(far_net["name"]):
                    pulled = "up"
                elif POWER_NET_GROUND.match(far_net["name"]):
                    pulled = "down"
                else:
                    continue
                if rule["bad_pull"] and pulled == rule["bad_pull"]:
                    bad_pull_found = True
                    findings.append((rule["severity"],
                        f"{ref} pin {pin} ({pname}) has a pull-{pulled} "
                        f"({other_ref}, to {far_net['name']}) on net "
                        f"'{net['name']}' — {rule['note']}"))
            if not bad_pull_found:
                checked_strapping.append(f"{pname} ({ref} pin {pin})")

    if not findings:
        clean = ", ".join(checked_strapping) if checked_strapping else "none present"
        print(f"check_pins: {', '.join(mcu_refs)} — no strapping-pin hazards found.")
        print(f"  strapping pins checked clean: {clean}")
        sys.exit(0)

    order = {"error": 0, "warning": 1, "info": 2}
    findings.sort(key=lambda f: order.get(f[0], 3))

    had_error = False
    for severity, message in findings:
        had_error = had_error or severity == "error"
        print(f"[{severity.upper()}] {message}")

    if checked_strapping:
        print(f"\nstrapping pins checked clean: {', '.join(checked_strapping)}")

    print()
    if had_error:
        print("check_pins: FAILED — resolve ERROR-severity findings above.")
        sys.exit(1)
    print("check_pins: passed with warnings/info above — review before fab.")
    sys.exit(0)


if __name__ == "__main__":
    main()

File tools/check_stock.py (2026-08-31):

#!/usr/bin/env python3
"""
Check LCSC stock (and existence) for every LCSC Part # in a BOM CSV before
it goes anywhere near a JLCPCB upload.

LCSC's product page embeds live stock data as server-rendered JSON, so a
plain GET with a browser User-Agent is enough - no API key, no headless
browser. For each LCSC code we check that the page's own productCode
actually matches what we asked for (an invalid/delisted code silently
redirects to an unrelated part instead of 404ing - this is exactly what
happened with a bogus code that looked plausible but wasn't real) and
that stockNumber is above a minimum threshold.

Also checks JLCPCB's own Basic/Extended classification for each part
(rendered as a "Basic"/"Extended" badge on jlcpcb.com/partdetail pages,
not shown on LCSC's listings at all). Extended parts carry a per-part-
type handling fee plus usually higher unit cost on top of it - this
doesn't fail the build, just reports Extended parts at the end so a
cost pass doesn't require re-auditing the whole BOM by hand again.

Usage:
    tools/check_stock.py <bom.csv> [--min-stock N]

Exits non-zero if any part is invalid or out of stock, so it can gate
fab.sh the same way ERC/DRC/check_pins.py do.
"""

import argparse
import csv
import re
import sys
import urllib.error
import urllib.request

UA = "Mozilla/5.0 (Windows NT 10.0; Win64; x64) AppleWebKit/537.36 (KHTML, like Gecko) Chrome/120.0 Safari/537.36"


def fetch_stock(code: str):
    """Return (ok, stock_number, actual_product_code, error_message)."""
    url = f"https://www.lcsc.com/product-detail/{code}.html"
    req = urllib.request.Request(url, headers={"User-Agent": UA})
    try:
        with urllib.request.urlopen(req, timeout=20) as resp:
            text = resp.read().decode("utf-8", errors="replace")
    except (urllib.error.URLError, TimeoutError) as e:
        return False, None, None, f"fetch failed: {e}"

    code_m = re.search(r'"productCode":"([^"]+)"', text)
    actual_code = code_m.group(1) if code_m else None
    stock_m = re.search(r'"stockNumber":(\d+)', text)
    stock = int(stock_m.group(1)) if stock_m else None

    if actual_code is None or stock is None:
        return False, None, actual_code, "couldn't find product data on page (code may not exist)"
    if actual_code != code:
        return False, stock, actual_code, f"redirected to a different part ({actual_code}) - code is invalid/delisted"
    return True, stock, actual_code, None


def fetch_classification(code: str):
    """Return 'Basic', 'Extended', or None if it can't be determined."""
    url = f"https://jlcpcb.com/partdetail/{code}"
    req = urllib.request.Request(url, headers={"User-Agent": UA})
    try:
        with urllib.request.urlopen(req, timeout=20) as resp:
            text = resp.read().decode("utf-8", errors="replace")
    except (urllib.error.URLError, TimeoutError):
        return None
    m = re.search(r'text-\[10px\] text-jlc-primary">([A-Za-z]+)', text)
    return m.group(1) if m else None


def main():
    ap = argparse.ArgumentParser()
    ap.add_argument("bom_csv")
    ap.add_argument("--min-stock", type=int, default=1,
                     help="warn if stock is below this (default: 1, i.e. only flag zero)")
    args = ap.parse_args()

    with open(args.bom_csv, newline="", encoding="utf-8") as f:
        rows = list(csv.DictReader(f))

    lcsc_col = None
    for candidate in ("LCSC Part #", "LCSC"):
        if rows and candidate in rows[0]:
            lcsc_col = candidate
            break
    if lcsc_col is None:
        print("check_stock: no LCSC column found in BOM - nothing to check", file=sys.stderr)
        sys.exit(0)

    problems = []
    extended = []
    checked = 0
    for row in rows:
        code = row.get(lcsc_col, "").strip()
        designator = row.get("Designator", "?")
        if not code:
            problems.append((designator, code, "no LCSC code set"))
            continue
        checked += 1
        ok, stock, actual_code, err = fetch_stock(code)
        if not ok:
            problems.append((designator, code, err))
            continue

        classification = fetch_classification(code)
        tag = f", {classification}" if classification else ""
        if stock < args.min_stock:
            problems.append((designator, code, f"stock is {stock} (below minimum {args.min_stock})"))
        else:
            print(f"[OK] {designator} ({code}): {stock} in stock{tag}")
        if classification == "Extended":
            extended.append((designator, code))

    print(f"\ncheck_stock: checked {checked} parts, {len(problems)} problem(s)")
    if extended:
        print(f"\n{len(extended)} Extended part(s) (handling fee + usually pricier - "
              f"worth a Basic-equivalent pass if cost matters):")
        for designator, code in extended:
            print(f"  {designator} ({code})")

    if problems:
        for designator, code, msg in problems:
            print(f"[PROBLEM] {designator} ({code or 'no code'}): {msg}")
        sys.exit(1)
    sys.exit(0)


if __name__ == "__main__":
    main()

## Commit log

2026-08-28 Initial repo: KiCad .gitignore, README, board dir layout
    Claude-Session: https://claude.ai/code/session_01EYL2kmELzktnjUswxt3rrB
2026-08-28 Add tray-board KiCad project (hydroponics_tray_controller)
    KiCad 10 project as drawn on desktop. ERC/DRC baseline captured separately;
    real findings so far: board-name text on F.Cu colliding with GND zone,
    ESP32 symbol instance out of sync with New_Library.
    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
    [hydroponics_tray_controller.kicad_pcb, hydroponics_tray_controller.kicad_sch]
2026-08-28 tray-board: fix ERC/DRC - sync U1 symbol, move board text to silkscreen
    - Update U1 (ESP32) symbol instance from New_Library (clears lib_symbol_mismatch)
    - Move "Gostwyck Hydroponics TrayController v0.1" text from F.Cu to F.Silkscreen
    (was colliding with the top_gnd pour at 0mm clearance)
    ERC and DRC now both clean.
    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
    [hydroponics_tray_controller.kicad_pcb, hydroponics_tray_controller.kicad_sch]
2026-08-28 Add tools/fab.sh - regenerate fab/assembly outputs via kicad-cli
    Runs ERC + DRC (fails on any error/warning), then exports trimmed gerbers
    (fab layers only), Excellon drill + map, SMD-only pick-and-place, and BOM
    to <board-dir>/production/ (git-ignored), plus a gerber zip.
    Fix .gitignore: production/ and gerbers/ were anchored to repo root and so
    didn't match tray-board/production/ - unanchored them.
    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
2026-08-28 README: comms architecture, fab.sh usage, current board status
    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
2026-08-28 docs: capture automated-documentation TODO
    Generate a browsable project site from the repo (board renders, 3D/gerber/BOM
    links, deployment manual) and fold doc updates into the deploy process.
    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
2026-08-30 Add reservoir-board KiCad project (hydroponics_reservoir_controller)
    Current state: schematic largely done (ERC clean except the same U1 ESP32
    lib_symbol_mismatch as tray-board), PCB layout in progress - 129 ratsnest
    connections still unrouted (GND/3V3/5V/12V pours + channel signals), plus
    one R30/R31 courtyard overlap and some silkscreen overlaps to tidy.
    Board: 8x low-side MOSFET channels (Q1-Q8 + flyback D3-D10) for fill/dosing
    pumps, 2x fan control with tach, ultrasonic level (TRIG/ECHO), I2C + 1-Wire
    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
    [hydroponics_reservoir_controller.kicad_pcb, hydroponics_reservoir_controller.kicad_sch]
2026-08-30 tray-board: replace ST7789 display connector with ILI9341 touch + SD card
    J2 is now a 14-pin header matching the actual ILI9341/XPT2046 touch
    display (VCC, GND, CS, RESET, DC, MOSI, SCK, LED, MISO, T_CLK, T_CS,
    T_DIN, T_DO, T_IRQ), replacing the old 8-pin no-touch ST7789 wiring.
    Added J3, a separate 4-pin SD card connector sharing the display SPI
    bus with its own CS line. New signals use previously-unused ESP32
    GPIOs 14, 19, 34, 35. Verified via KiCad 10 ERC and netlist export.
    PCB footprints synced from the updated schematic (Update PCB from
    Schematic) - placement and routing for the new pins still needed.
    README updated with the corrected display spec and pin list.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
    [hydroponics_tray_controller.kicad_pcb, hydroponics_tray_controller.kicad_sch]
2026-08-31 tools: add MCU pin-safety check, run before every fab build
    New tools/check_pins.py exports the schematic netlist and checks the
    MCU's pin usage for hardware hazards ERC doesn't catch: ESP32 strapping
    pins (GPIO0/2/5/12/15) with an external pull that fights their required
    boot-time level, GPIO6-11 (internal flash, must stay untouched), and
    UART0 (GPIO1/3, reserved for USB-serial/flashing). Also flags input-only
    pins (34/35/36/39) as a reminder to confirm they're never used where the
    MCU needs to drive the line.
    Wired into tools/fab.sh right after ERC so a bad strap fails the build
    the same way an ERC/DRC violation does.
    Claude-Session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
    [check_pins.py]
2026-08-31 reservoir-board: add PCB routing (traces/vias)
    Route the hydroponics_reservoir_controller board layout - adds ~600
    track segments and vias. Minor designator-order reshuffle in the
    project file.
    Claude-Session: https://claude.ai/code/session_01EaqMDfPd3Yu8GaTXYhbk9d
    [hydroponics_reservoir_controller.kicad_pcb]
2026-08-31 JLCPCB prep: fab.sh cleanup, DNP the ESP32 module, BOM part-value fixes
    tools/fab.sh:
    - Gerbers use Protel extensions (JLCPCB's preferred naming) instead of
    --no-protel-ext.
    - Drill export splits PTH/NPTH into separate Excellon files
    (--excellon-separate-th) instead of one merged file.
    - BOM export now pulls the LCSC field (matching what's actually used in
    the schematics) instead of a nonexistent MPN field, groups by
    Value+Footprint+LCSC so parts sharing a value but not an LCSC code
    don't get merged together and silently lose their code, and excludes
    DNP parts.
    - Pick-and-place (now named *-cpl.csv) already excluded DNP/THT; BOM
    now matches.
    - Final zip only includes the gerber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
    [hydroponics_reservoir_controller.kicad_sch, hydroponics_tray_controller.kicad_sch]
2026-08-31 reservoir-board: populate LCSC part numbers for the full BOM
    Added an LCSC property to every BOM line that was missing one (75
    component references across resistors, capacitors, connectors,
    terminal blocks, MOSFETs, ICs, the inductor, and the fuse), researched
    and cross-checked against LCSC's own product listings rather than
    assumed. D1/D3 already had codes from earlier manual work; applied
    D3's SS14 code to the other seven SS14 diodes (D4-D10) so they merge
    into one BOM line instead of sitting uncoded.
    F1 (resettable fuse) is C207091 (Littelfuse 2920L500/16MR) - 2920
    package matches the existing footprint, 5A hold current, 16V rather
    than the originally-wanted 30V (accepted knowingly; LCSC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
    [hydroponics_reservoir_controller.kicad_sch]
2026-08-31 tools/fab.sh: fix production/ output path for nested board dirs
    out was computed from the board-dir argument (e.g. reservoir-board/),
    but the actual KiCad project lives one level deeper
    (reservoir-board/hydroponics_reservoir_controller/). Output was
    landing as a sibling of the project folder instead of inside it.
    Derive out from the found .kicad_pcb's own directory instead, so it
    works regardless of nesting depth.
    Claude-Session: https://claude.ai/code/session_01QYbZEgBzGJ6rSai1ie8nG1
2026-08-31 Fix ESP32 socket footprint: mislabeled attr broke DNP/CPL export
    The ESP32_DevKit_30Pin footprint (both boards' Library.pretty copies)
    was tagged (attr smd) despite every pad being thru_hole - a footprint
    authoring mistake. Combined with DNP being a PCB-level attribute that
    only syncs from the schematic via "Update PCB from Schematic" (which
    never happened here since all my DNP work was CLI-only), this meant
    `pcb export pos --smd-only --exclude-dnp` neither excluded it as
    through-hole nor as DNP: U1 kept showing up in the CPL with no
    matching BOM line (which is DNP-excluded correctly, since that reads
    straight from the schematic).
    That CPL/BOM mismatch on a designator JLCPCB can't place any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
    [hydroponics_reservoir_controller.kicad_pcb, hydroponics_tray_controller.kicad_pcb]
2026-08-31 tools: post-process CPL into JLCPCB's exact expected format
    kicad-cli's `pcb export pos` has no header-customization flag (unlike
    `sch export bom`), so its raw CSV output uses KiCad's own column names
    (Ref, Val, Package, PosX, PosY, Rot, Side) and format conventions —
    not what JLCPCB's uploader expects. Checked against JLCPCB's own
    sample CPL file, the actual requirements are:
    - Exact headers: Designator, Mid X, Mid Y, Layer, Rotation
    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
2026-08-31 tools/fab.sh: disable BOM reference-range compression for JLCPCB
    kicad-cli's BOM grouping compressed consecutive designators into
    ranges (C5-C7, D3-D10, Q1-Q8, ...), but the CPL always lists each one
    individually (C5, C6, C7, ...). JLCPCB's uploader cross-matches BOM
    and CPL designators literally, so "C5-C7" in the BOM never matches
    "C5"/"C6"/"C7" in the CPL - it rejected both files as having missing
    designators. --ref-range-delimiter '' keeps the grouping (still one
    row per shared value/footprint/LCSC) but as a plain comma list
    (C5,C6,C7), matching what the CPL exports and what JLCPCB expects.
    Claude-Session: https://claude.ai/code/se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
2026-08-31 tools: split BOM into JLC-placed vs hand-solder shopping list
    The CPL is deliberately --smd-only (through-hole parts - connectors,
    terminal blocks, headers - are hand-soldered, not JLC-placed), but the
    BOM had no equivalent filter, so it still listed every part. JLCPCB's
    uploader rejects that as designators missing from the CPL.
    Added tools/filter_bom_to_cpl.py: restricts the BOM to exactly the
    CPL's designator set (kept as *-bom.csv, still grouped/quantity-
    correct), and writes everything it drops to *-hand-solder-bom.csv -
    a shopping list, LCSC codes included, for whatever you're sourcing
    and fitting yourself.
    Claude-Session: https: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
    [filter_bom_to_cpl.py]
2026-08-31 reservoir-board: fix 4 out-of-stock/invalid LCSC codes; add stock checker
    JLCPCB rejected the order over parts shortages (C8/C9, L1, R1) and
    "D3-D10 don't have parts defined." Checked each directly against LCSC:
    - C1508 (D3-D10, SS14) doesn't exist on LCSC at all - it 404s, or on a
    retry silently redirects to an unrelated part (C293349). This was
    the user's own prior manual-workflow data, never actually valid.
    Replaced with C466498 (High Diode SS14, SMA, verified in stock).
    - C105213 (C8,C9, 22uF 1206 X5R) and C2047389 (L1, Bourns
    SRP6060FA-4R7M) are both genuinely 0 stock on LCSC. Replaced with
    C338055 (TDK, same 22uF/25V/X5R/1206 spec) and C2046759 (Bourns
    SRP6060FA-100M, 10uH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
    [hydroponics_reservoir_controller.kicad_sch]
2026-08-31 reservoir-board: swap 7 Extended-classified parts for Basic equivalents
    JLCPCB charges a per-part-type handling fee for "Extended" parts (not
    pre-loaded on their SMT feeders) on top of generally higher per-unit
    cost, versus "Basic" parts which carry neither penalty. Checked every
    LCSC code in the BOM against JLCPCB's own Basic/Extended classification
    (scraped from the "Basic"/"Extended" badge JLCPCB renders on each part
    page - not shown on LCSC's own listings) and found 7 identical-or-
    equivalent-spec parts sitting on Extended listings for no real reason:
    - R1 (100k): C96346 (Yageo, Extended) -> C149504 - the exact same
    UNI-ROYAL 0805W8F1003T5E part as the original C17407, just a
    differ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
    [hydroponics_reservoir_controller.kicad_sch]
2026-08-31 reservoir-board: revert R2 - my Basic swap was actually still Extended
    Applied C2889622 for R2 (75k) on the assumption it was a Basic +/-5%
    part, based on it appearing in a JLCPCB parts-library search result
    alongside other Basic VO resistors - but never actually checked its
    own classification badge before committing. It's Extended. That left
    R2 with zero cost benefit over the original C17819 and worse tolerance
    for no reason. Reverted to C17819 (Extended, +/-1%, the correct choice
    originally). No genuine Basic 75k 0805 resistor exists on JLCPCB as
    far as I can find - checked three different candidates, all Extended.
    Also add Basic/Extended classification reporting to check_stock.py
    (same "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
    [hydroponics_reservoir_controller.kicad_sch]
2026-08-31 docs: add MSP2401 mechanical drawing for the tray-board display redesign
    LCD Wiki's MSP2401/MSP2402 2.4" ILI9341+XPT2046 module drawing - its
    14-pin table matches the tray-board display's pinout exactly, so it's
    very likely the same reference design. Gives dimensioned PCB outline,
    main header spacing, and mounting hole positions to work from for the
    connector footprint once the wider-display layout redesign starts.
    Noted in docs/TODO.md: the SD header position specifically isn't
    dimensioned in this drawing (shown as bare pads, not a connector) -
    needs measuring off the physical board before laying out J3.
    Claude-Session: https://claud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
2026-08-31 docs: confirm MSP2401 drawing matches the physical display board
    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
2026-08-31 tray-board: fix EN pin number drift and J3 pin4 dangling wire
    Same New_Library.kicad_sym drift as reservoir-board (EN pin number ""
    in the library file vs "30" in the schematic's cached copy, matching
    the ESP32_DevKit_30Pin footprint's pad "30") - tray-board's copy had
    the same stale "" left over, just never triggered ERC since nothing
    here referenced pin 30 by name at the time it was last checked.
    J3 (SD connector) pin 4's wire started 1.27mm short of the actual pin
    position - a leftover construction slip from when J3 was first added,
    surfaced now as a real ERC error after the pin got moved during the
    in-progress redesign. Fixed to reach the pin.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
    [hydroponics_tray_controller.kicad_sch]
2026-08-31 Consolidate custom KiCad library into a shared location
    New_Library.kicad_sym and Library.pretty existed as separate copies
    per board, which is exactly how the EN-pin-number and footprint-attr
    drift bugs happened twice (fixed independently on each copy earlier
    this session, and again just now on tray-board after the same drift
    resurfaced) - editing one copy silently leaves the other stale with no
    warning until ERC/DRC catches it on that specific board.
    Moved both to shared-library/ at the repo root; both boards'
    sym-lib-table/fp-lib-table now point there via
    ${KIPRJMOD}/../../shared-library/ instead of a local per-project copy.
    Library nicknames (New_Library, Library) are unchanged, so no l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
2026-08-31 Display footprint: add the SD header (J4) - it was dimensioned after all
    Misread the mechanical drawing's dimension chain earlier: the four
    stacked numbers (3.00, 6.51, 9.26, 2.17) below the top edge are each
    measured from that same top-edge datum, not sequential deltas from
    each other - so I mistook them for unrelated reference points and
    assumed the SD header (J4) wasn't dimensioned. It is: J4 sits at
    Y=6.51mm from the top edge, X=17.23mm from the left edge, 4 pins at
    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
2026-08-31 docs: update SD header status - dimensioned and built into the footprint now
    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
2026-08-31 tray-board: merge display+SD connector into one symbol, fix SD pad position, re-sync PCB
    - New_Library: merged the 14-pin main header and 4-pin SD header into a
    single Display_MSP2401_2.4in_Touch schematic symbol, matching the combined
    footprint's fixed connector spacing. J3 (standalone SD connector) removed;
    its nets are now carried by the merged symbol's SD1-SD4 pins.
    - Footprint: fixed SD1-SD4 pad Y-coordinate (6.51mm -> 3.00mm from the top
    edge) - they sit in the same row as the two top mounting holes, per the
    mechanical drawing.
    - Fixed H1-H4 mounting hole footprint (MountingHole_3.2mm_M3_Pad_Via ->
    MountingHole_3.2mm_M3) to match their "no connection" schematic symbol.
    - ki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
    [hydroponics_tray_controller.kicad_pcb, hydroponics_tray_controller.kicad_sch]
2026-09-01 tray-board: re-sync PCB, set min_clearance to 0.0
    Claude-Session: https://claude.ai/code/session_01VxeU7RBY2UcBHFLNmCs7rA
    [hydroponics_tray_controller.kicad_pcb]
2026-09-01 tray-board: ground plane fix, stitching, C3 ceramic swap, full JLC BOM
    - F.Cu ground zone was netless with island-removal off, filling as ~26
    isolated islands (DRC isolated_copper). Assigned to GND, islands removed.
    - Added ~18 GND stitching vias (ICs, decoupling caps, ESP32 centreline).
    - Mounting holes H1-H4 swapped to MountingHole_Pad symbols wired to GND;
    the _Pad_Via footprints now bond both pours at all four corners.
    - C3 changed from 10uF tantalum (EIA-3528-21, JLC Extended) to 10uF 25V
    X5R 0805 ceramic (C15850, Basic) - board is now Basic-only.
    - Populated LCSC part numbers for all 13 SMD parts, stock/Basic-checked.
    - Restored the board silkscreen title dropped in the earlier r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
    [hydroponics_tray_controller.kicad_pcb, hydroponics_tray_controller.kicad_sch]
2026-09-01 tools: KICAD_CLI override, zone refill on DRC, STEP export
    - fab.sh honours $KICAD_CLI so an older system kicad-cli can be bypassed
    (e.g. the Windows KiCad 10 binary from WSL).
    - DRC runs with --refill-zones; gerber export with --check-zones.
    - New STEP export step for mechanical CAD (no --no-dnp: socketed modules
    are physically fitted).
    - check_pins.py honours $KICAD_CLI for its netlist export.
    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
2026-09-01 tray-board: rework ESP32 socket footprint - 1.0mm holes, silk, 3D model
    The ESP32 DevKit socket footprint was 30 bare pads with 0.8mm holes - too
    tight for ~0.64mm header pins once splay + fab tolerance are added, and the
    module (a wider 26.2mm-row variant, not the 25.4mm DOIT standard) barely fits.
    - Holes 0.8 -> 1.0mm, pads 1.27 -> 1.6mm.
    - Row spacing kept at 26.2mm (measured off the physical module).
    - Added pin-1 square pad + silk chevron, silk row marks, F.Fab outline,
    F.CrtYd courtyard (sized to the pad field + margin).
    - attr back to through_hole (had drifted to smd - same bug as a7a317e).
    - 3D model wired in via a portable ${KIPRJMOD}/../../models/ path.
    - ESP32 area rerouted for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
    [TFT LCD 2.4 inch ILI9341 touch.step, esp32_30pin.step, hydroponics_tray_controller.kicad_pcb]
2026-09-08 tray-board: connector pinout silkscreen, production release
    Add per-pin function labels + connector-name legends on F.Silkscreen for
    J4 (Bus: 5V/B/A/GND), J5 (i2c: XS2/XS1/SCL/SDA/GND/3v3), J6 (1Wire:
    3V3/GND/DAT) and J1 (RS485 term jumper). Netlist-verified; DRC clean incl.
    silk-over-copper. Fab package regenerated via tools/fab.sh (ERC/DRC 0,
    BOM all-Basic, CPL 13 placements). Test points deferred to next board.
    Claude-Session: https://claude.ai/code/session_018B5wz5uLqNpf9KQR3CBAQm
    [hydroponics_tray_controller.kicad_pcb]
